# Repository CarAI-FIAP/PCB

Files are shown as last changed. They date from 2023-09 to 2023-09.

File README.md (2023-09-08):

# PCB
Placa em PCB para centralizar as conexões. Projeto em KiCAD

Vista frontal da superficie superior
Vista frontal da superficie inferior
Vista traseira da superficie superior
Vista superior da superficie superior

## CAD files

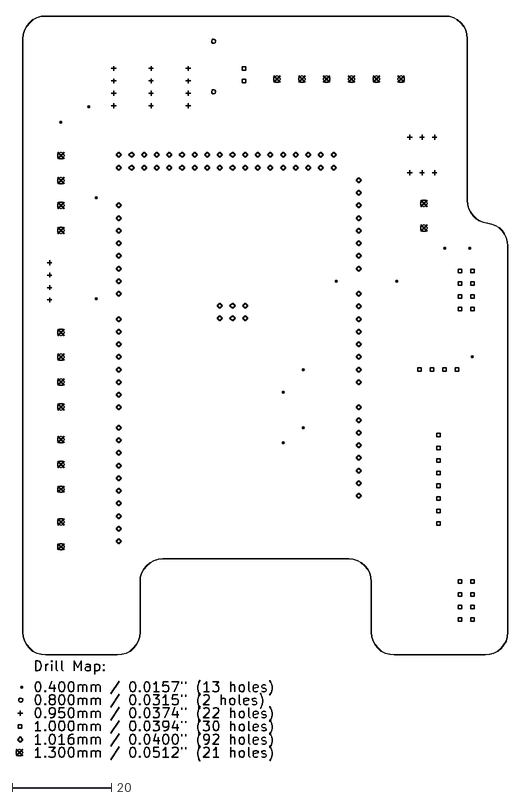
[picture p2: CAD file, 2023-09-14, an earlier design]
V3/Manufatura/PCB V3-PTH-drl_map.dxf
98.9 x 149.9

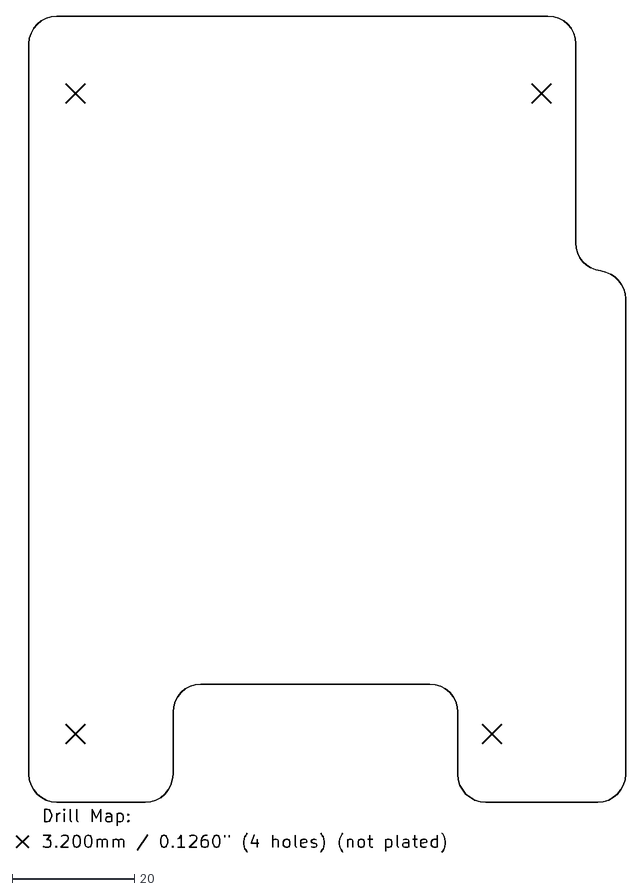
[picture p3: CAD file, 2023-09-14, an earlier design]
V3/Manufatura/PCB V3-NPTH-drl_map.dxf
99.6 x 136.7

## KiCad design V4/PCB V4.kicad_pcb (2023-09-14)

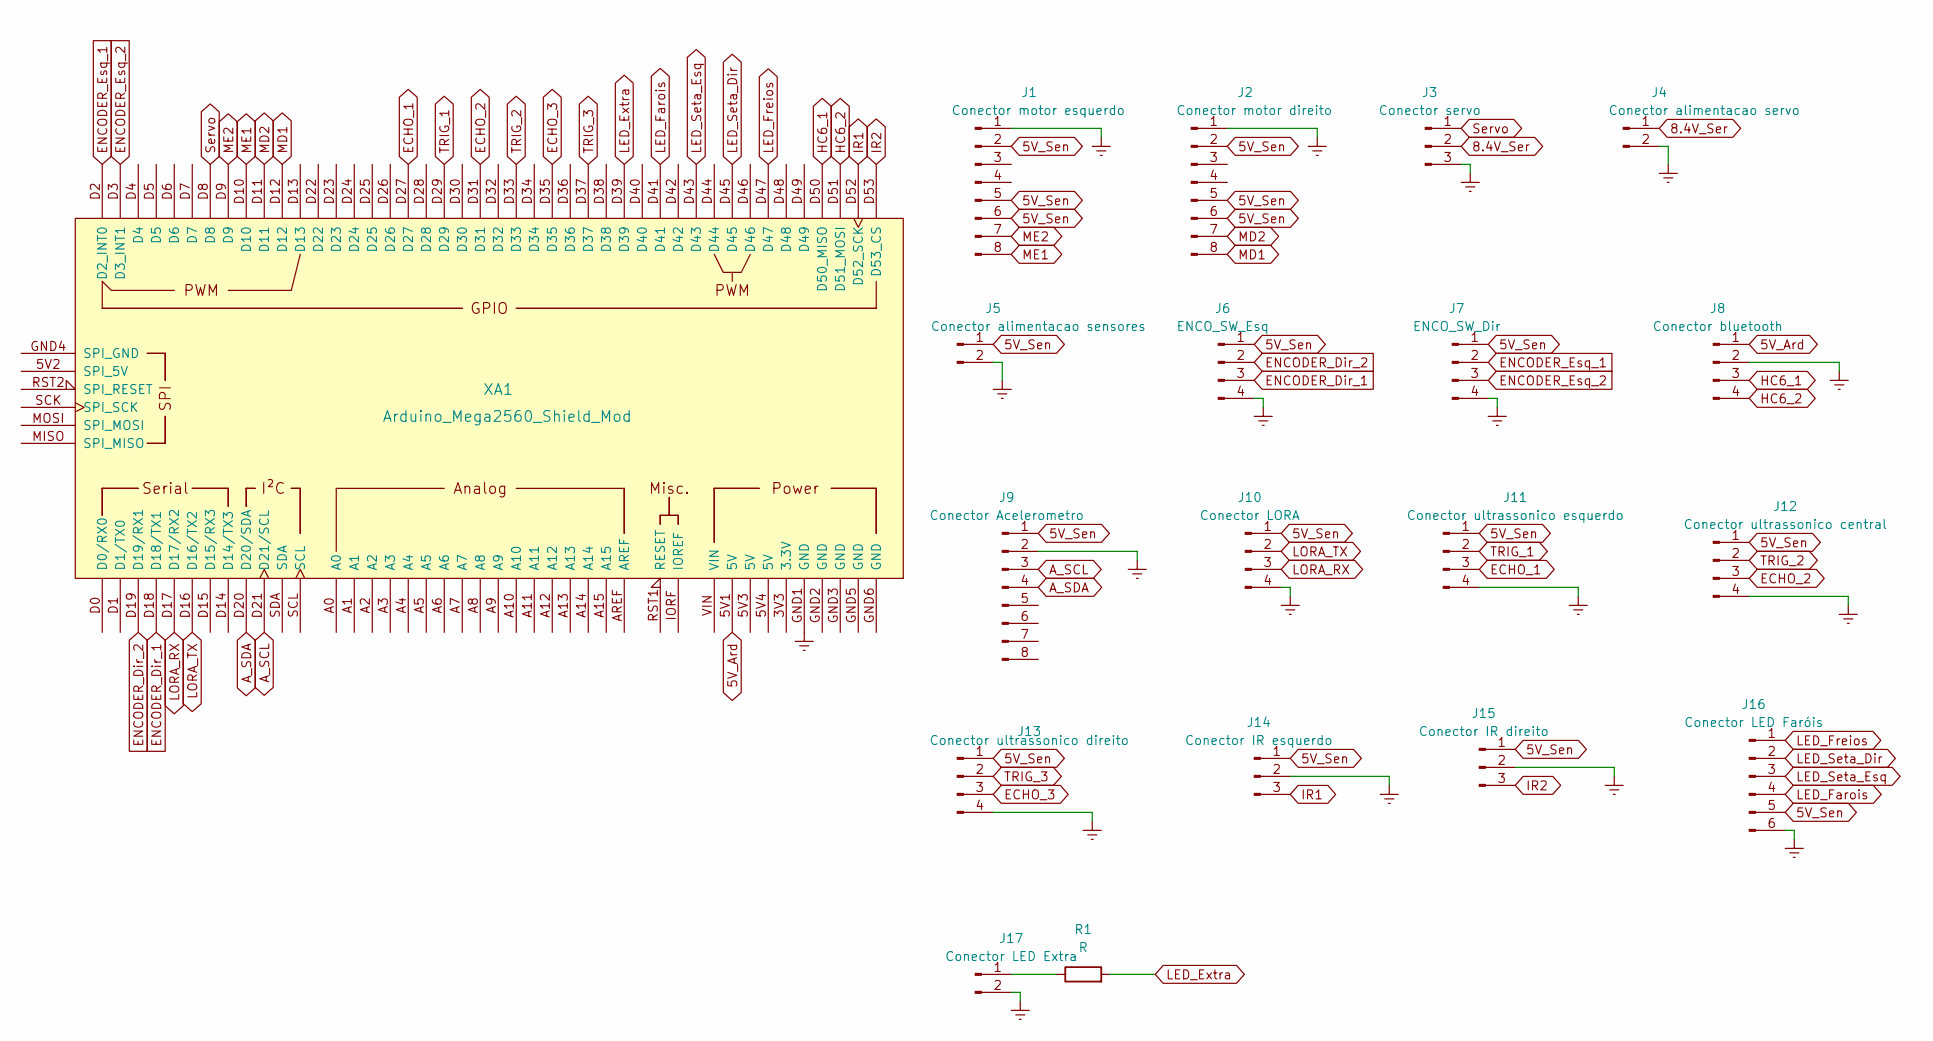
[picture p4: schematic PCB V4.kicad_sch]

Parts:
J1: Conector motor esquerdo; PinSocket_2x04_P2.54mm_Vertical
J2: Conector motor direito; PinSocket_2x04_P2.54mm_Vertical
J3: Conector servo; TerminalBlock_Phoenix_MKDS-1,5-3_1x03_P5.00mm_Horizontal
J4: Conector alimentacao servo; TerminalBlock_Phoenix_MKDS-1,5-2_1x02_P5.00mm_Horizontal
J5: Conector alimentacao sensores; TerminalBlock_Phoenix_MKDS-1,5-2_1x02_P5.00mm_Horizontal
J6: ENCO_SW_Esq; TerminalBlock_Phoenix_MKDS-1,5-4_1x04_P5.00mm_Horizontal
J7: ENCO_SW_Dir; TerminalBlock_Phoenix_MKDS-1,5-4_1x04_P5.00mm_Horizontal
J8: Conector bluetooth; PinSocket_1x04_P2.54mm_Vertical
J9: Conector Acelerometro; PinSocket_1x08_P2.54mm_Vertical
J10: Conector LORA; JST_XH_B4B-XH-A_1x04_P2.50mm_Vertical
J11: Conector ultrassonico esquerdo; JST_XH_B4B-XH-A_1x04_P2.50mm_Vertical
J12: Conector ultrassonico central; JST_XH_B4B-XH-A_1x04_P2.50mm_Vertical
J13: Conector ultrassonico direito; JST_XH_B4B-XH-A_1x04_P2.50mm_Vertical
J14: Conector IR esquerdo; JST_XH_B3B-XH-A_1x03_P2.50mm_Vertical
J15: Conector IR direito; JST_XH_B3B-XH-A_1x03_P2.50mm_Vertical
J16: Conector LED Faróis; TerminalBlock_Phoenix_MKDS-1,5-6_1x06_P5.00mm_Horizontal
J17: Conector LED Extra; JST_XH_B2B-XH-A_1x02_P2.50mm_Vertical
R1: R; R_Axial_DIN0207_L6.3mm_D2.5mm_P10.16mm_Horizontal
XA1: Arduino_Mega2560_Shield_Mod; Arduino_Mega2560_R3_Shield_No_Holes

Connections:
5V_Ard: J8.1, XA1.5V1 (5V)
5V_Sen: J1.2, J1.5, J1.6, J2.2, J2.5, J2.6, J5.1, J6.1, J7.1, J9.1, J10.1, J11.1, J12.1, J13.1, J14.1, J15.1, J16.5
8.4V_Ser: J3.2, J4.1
A_SCL: J9.3, XA1.D21 (D21/SCL)
A_SDA: J9.4, XA1.D20 (D20/SDA)
ECHO_1: J11.3, XA1.D27
ECHO_2: J12.3, XA1.D31
ECHO_3: J13.3, XA1.D35
ENCODER_Dir_1: J6.3, XA1.D18 (D18/TX1)
ENCODER_Dir_2: J6.2, XA1.D19 (D19/RX1)
ENCODER_Esq_1: J7.2, XA1.D2 (D2_INT0)
ENCODER_Esq_2: J7.3, XA1.D3 (D3_INT1)
Earth: J1.1, J2.1, J3.3, J4.2, J5.2, J6.4, J7.4, J8.2, J9.2, J10.4, J11.4, J12.4, J13.4, J14.2, J15.2, J16.6, J17.2, XA1.GND1 (GND)
HC6_1: J8.3, XA1.D50 (D50_MISO)
HC6_2: J8.4, XA1.D51 (D51_MOSI)
IR1: J14.3, XA1.D52 (D52_SCK)
IR2: J15.3, XA1.D53 (D53_CS)
LED_Extra: R1.2, XA1.D39
LED_Farois: J16.4, XA1.D41
LED_Freios: J16.1, XA1.D47
LED_Seta_Dir: J16.2, XA1.D45
LED_Seta_Esq: J16.3, XA1.D43
LORA_RX: J10.3, XA1.D17 (D17/RX2)
LORA_TX: J10.2, XA1.D16 (D16/TX2)
MD1: J2.8, XA1.D12
MD2: J2.7, XA1.D11
ME1: J1.8, XA1.D10
ME2: J1.7, XA1.D9
unnamed: J17.1, R1.1
Servo: J3.1, XA1.D8
TRIG_1: J11.2, XA1.D29
TRIG_2: J12.2, XA1.D33
TRIG_3: J13.2, XA1.D37

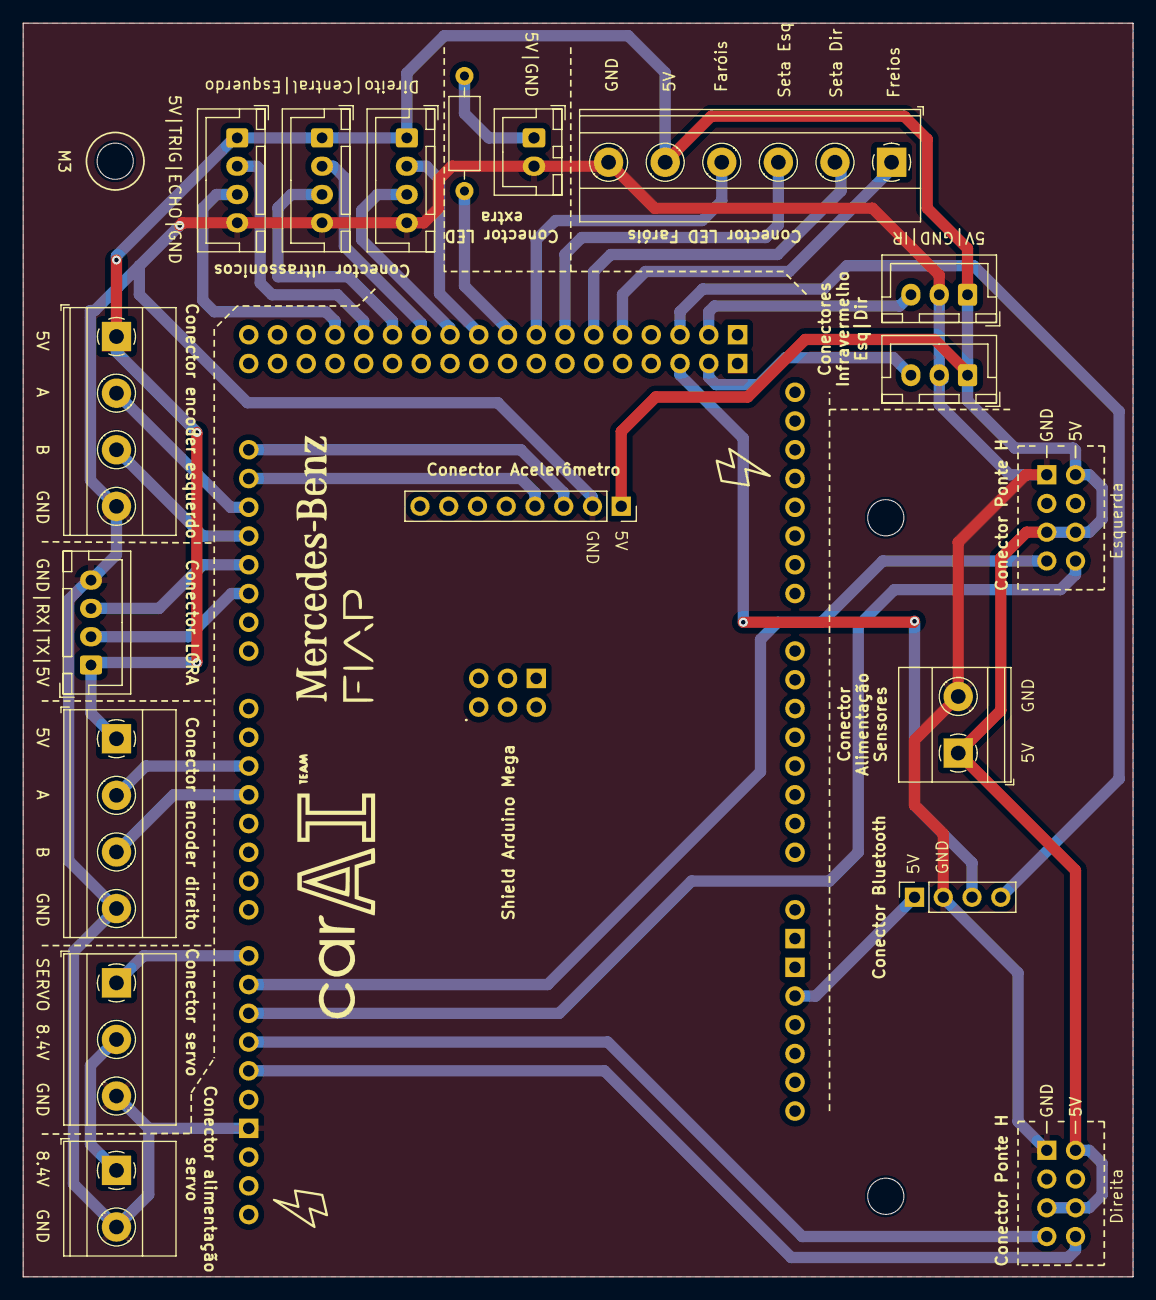
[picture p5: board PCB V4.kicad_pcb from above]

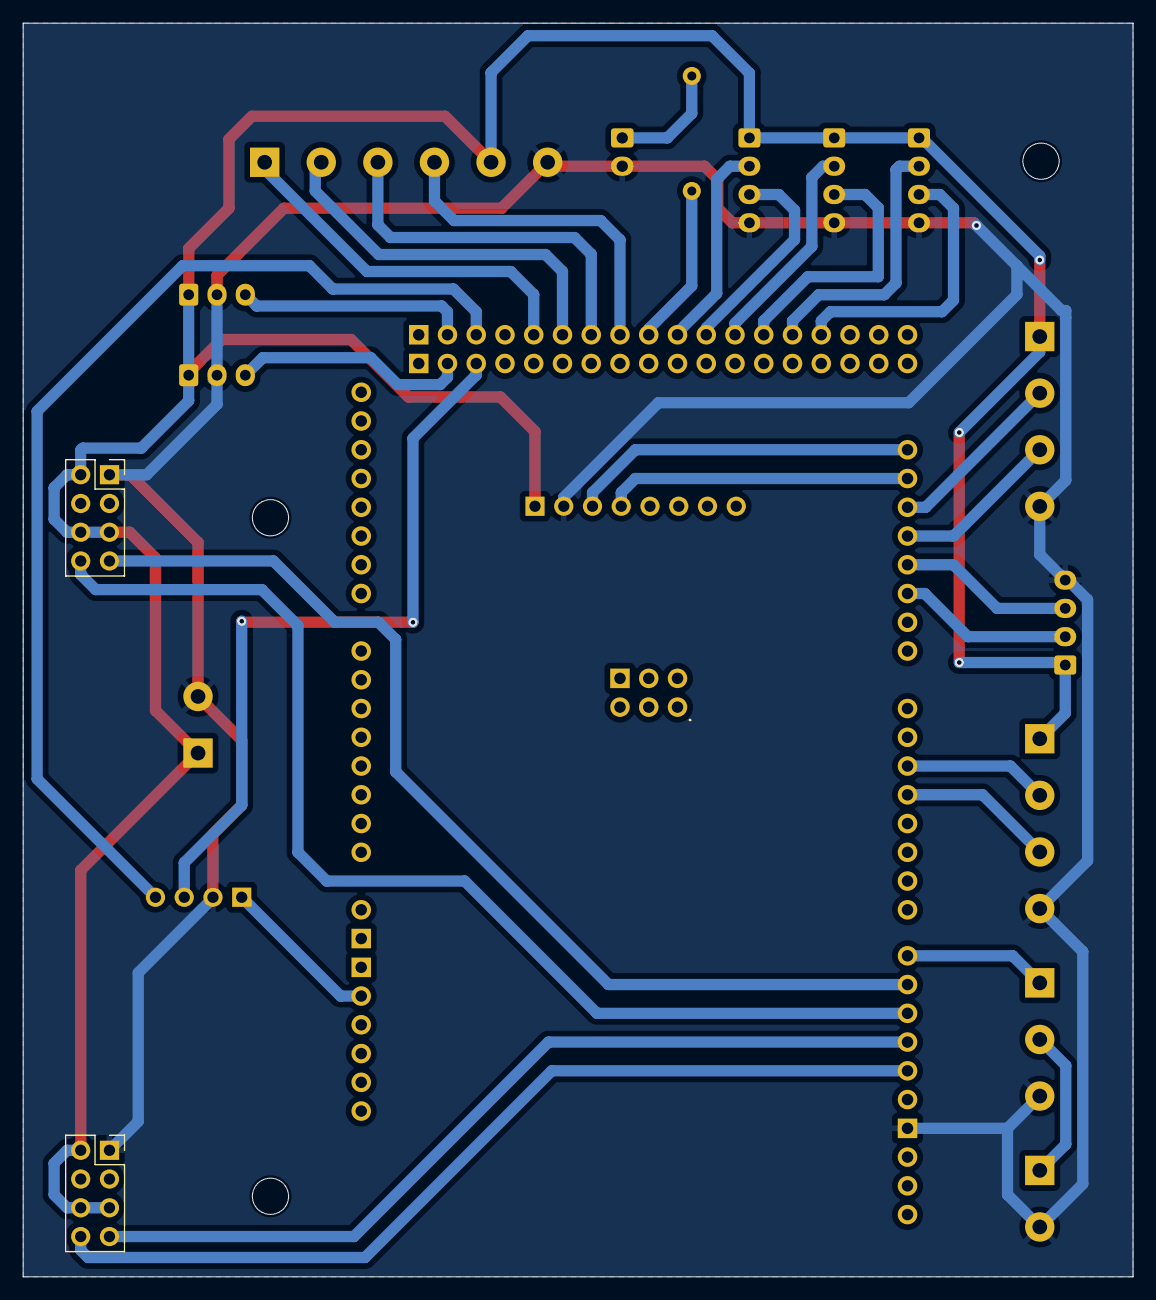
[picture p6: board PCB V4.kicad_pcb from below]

Board: 2 copper layers, 98.0 x 110.7 mm, 19 parts (2 on the bottom side), 33 nets.

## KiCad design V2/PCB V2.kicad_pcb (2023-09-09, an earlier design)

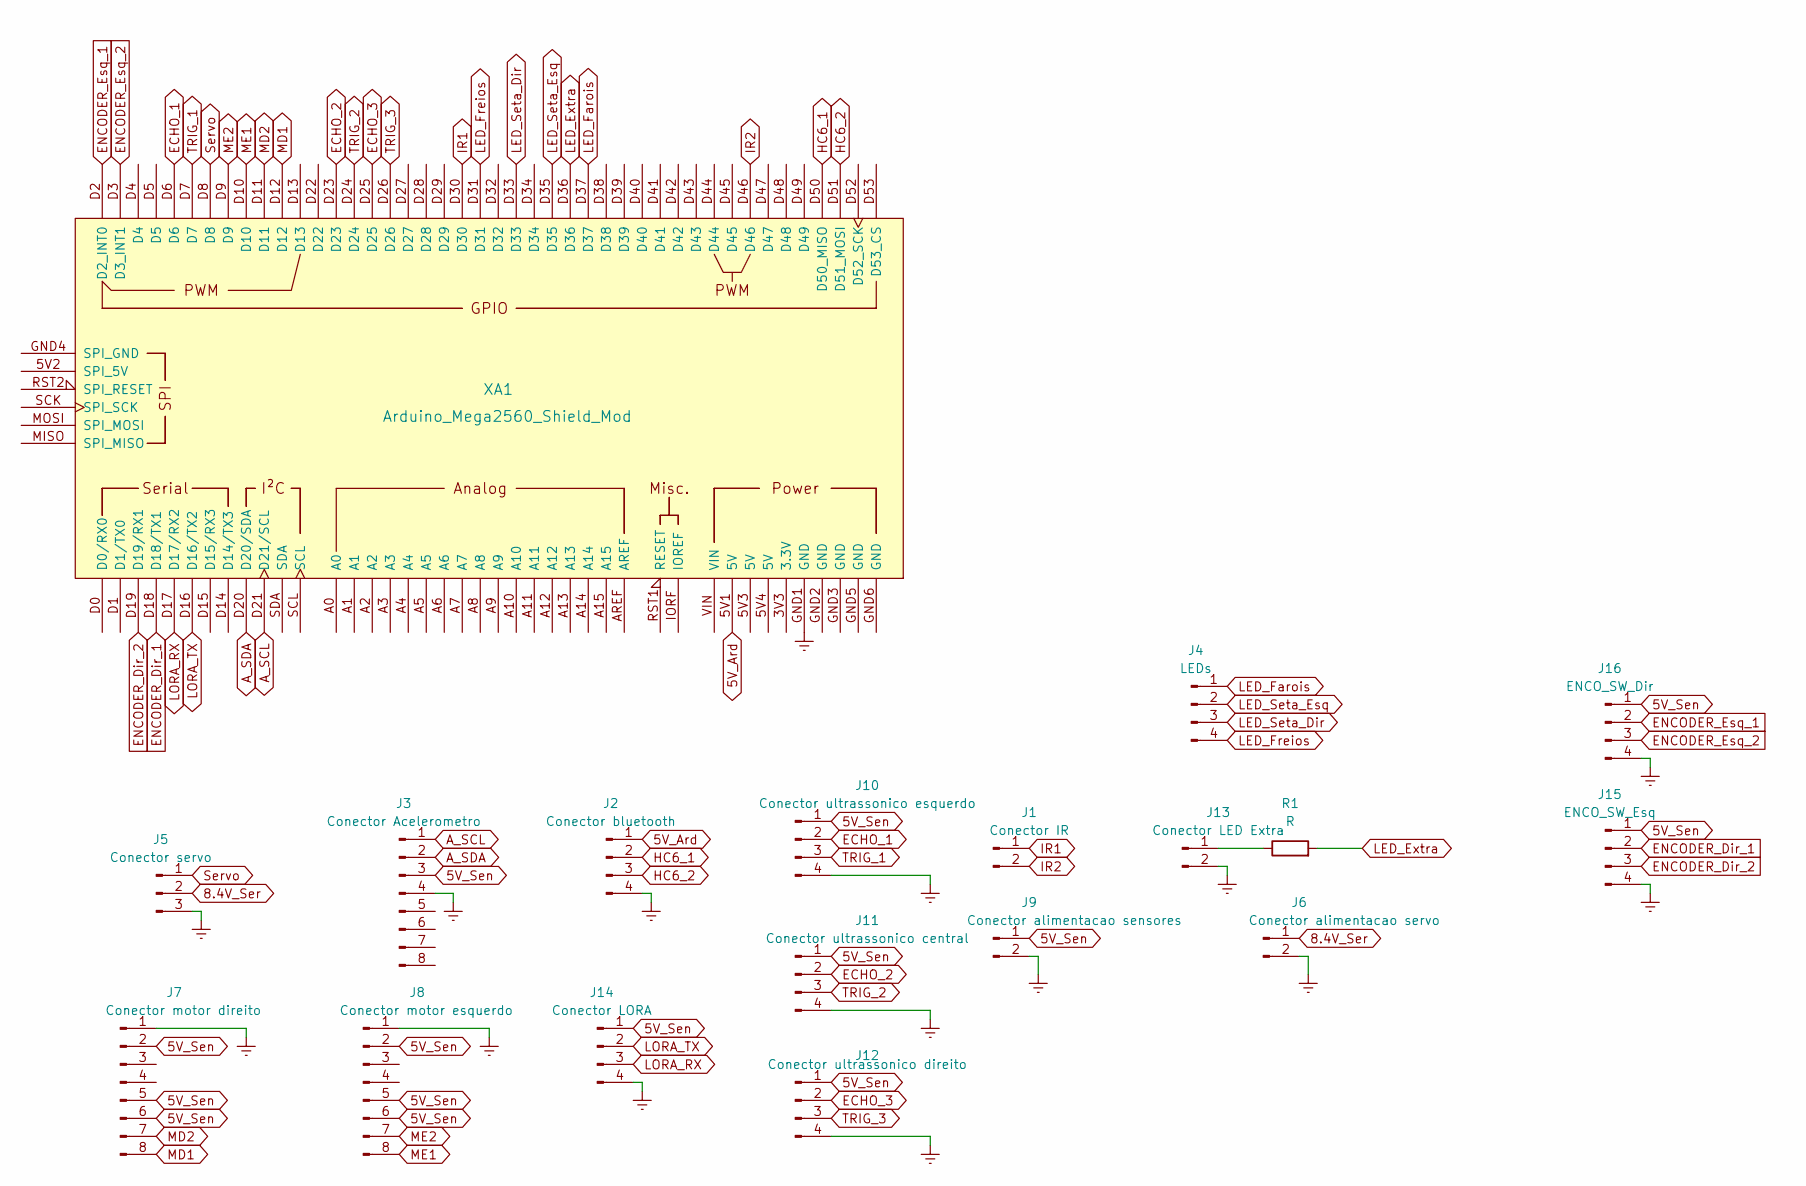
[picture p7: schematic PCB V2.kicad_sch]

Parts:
J1: Conector IR; JST_XH_B2B-XH-A_1x02_P2.50mm_Vertical
J2: Conector bluetooth; PinSocket_1x04_P2.54mm_Vertical
J3: Conector Acelerometro; PinSocket_1x08_P2.54mm_Vertical
J4: LEDs; TerminalBlock_Phoenix_MKDS-1,5-4_1x04_P5.00mm_Horizontal
J5: Conector servo; TerminalBlock_Phoenix_MKDS-1,5-3_1x03_P5.00mm_Horizontal
J6: Conector alimentacao servo; TerminalBlock_Phoenix_MKDS-1,5-2_1x02_P5.00mm_Horizontal
J7: Conector motor direito; PinSocket_2x04_P2.54mm_Vertical
J8: Conector motor esquerdo; PinSocket_2x04_P2.54mm_Vertical
J9: Conector alimentacao sensores; TerminalBlock_Phoenix_MKDS-1,5-2_1x02_P5.00mm_Horizontal
J10: Conector ultrassonico esquerdo; JST_XH_B4B-XH-A_1x04_P2.50mm_Vertical
J11: Conector ultrassonico central; JST_XH_B4B-XH-A_1x04_P2.50mm_Vertical
J12: Conector ultrassonico direito; JST_XH_B4B-XH-A_1x04_P2.50mm_Vertical
J13: Conector LED Extra; JST_XH_B2B-XH-A_1x02_P2.50mm_Vertical
J14: Conector LORA; JST_XH_B4B-XH-A_1x04_P2.50mm_Vertical
J15: ENCO_SW_Esq; TerminalBlock_Phoenix_MKDS-1,5-4_1x04_P5.00mm_Horizontal
J16: ENCO_SW_Dir; TerminalBlock_Phoenix_MKDS-1,5-4_1x04_P5.00mm_Horizontal
R1: R; R_Axial_DIN0207_L6.3mm_D2.5mm_P10.16mm_Horizontal
XA1: Arduino_Mega2560_Shield_Mod; Arduino_Mega2560_R3_Shield_Sem_furo

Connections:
5V_Ard: J2.1, XA1.5V1 (5V)
5V_Sen: J3.3, J7.2, J7.5, J7.6, J8.2, J8.5, J8.6, J9.1, J10.1, J11.1, J12.1, J14.1, J15.1, J16.1
8.4V_Ser: J5.2, J6.1
A_SCL: J3.1, XA1.D21 (D21/SCL)
A_SDA: J3.2, XA1.D20 (D20/SDA)
ECHO_1: J10.2, XA1.D6
ECHO_2: J11.2, XA1.D23
ECHO_3: J12.2, XA1.D25
ENCODER_Dir_1: J15.2, XA1.D18 (D18/TX1)
ENCODER_Dir_2: J15.3, XA1.D19 (D19/RX1)
ENCODER_Esq_1: J16.2, XA1.D2 (D2_INT0)
ENCODER_Esq_2: J16.3, XA1.D3 (D3_INT1)
Earth: J2.4, J3.4, J5.3, J6.2, J7.1, J8.1, J9.2, J10.4, J11.4, J12.4, J13.2, J14.4, J15.4, J16.4, XA1.GND1 (GND)
HC6_1: J2.2, XA1.D50 (D50_MISO)
HC6_2: J2.3, XA1.D51 (D51_MOSI)
IR1: J1.1, XA1.D30
IR2: J1.2, XA1.D46
LED_Extra: R1.2, XA1.D36
LED_Farois: J4.1, XA1.D37
LED_Freios: J4.4, XA1.D31
LED_Seta_Dir: J4.3, XA1.D33
LED_Seta_Esq: J4.2, XA1.D35
LORA_RX: J14.3, XA1.D17 (D17/RX2)
LORA_TX: J14.2, XA1.D16 (D16/TX2)
MD1: J7.8, XA1.D12
MD2: J7.7, XA1.D11
ME1: J8.8, XA1.D10
ME2: J8.7, XA1.D9
unnamed: J13.1, R1.1
Servo: J5.1, XA1.D8
TRIG_1: J10.3, XA1.D7
TRIG_2: J11.3, XA1.D24
TRIG_3: J12.3, XA1.D26

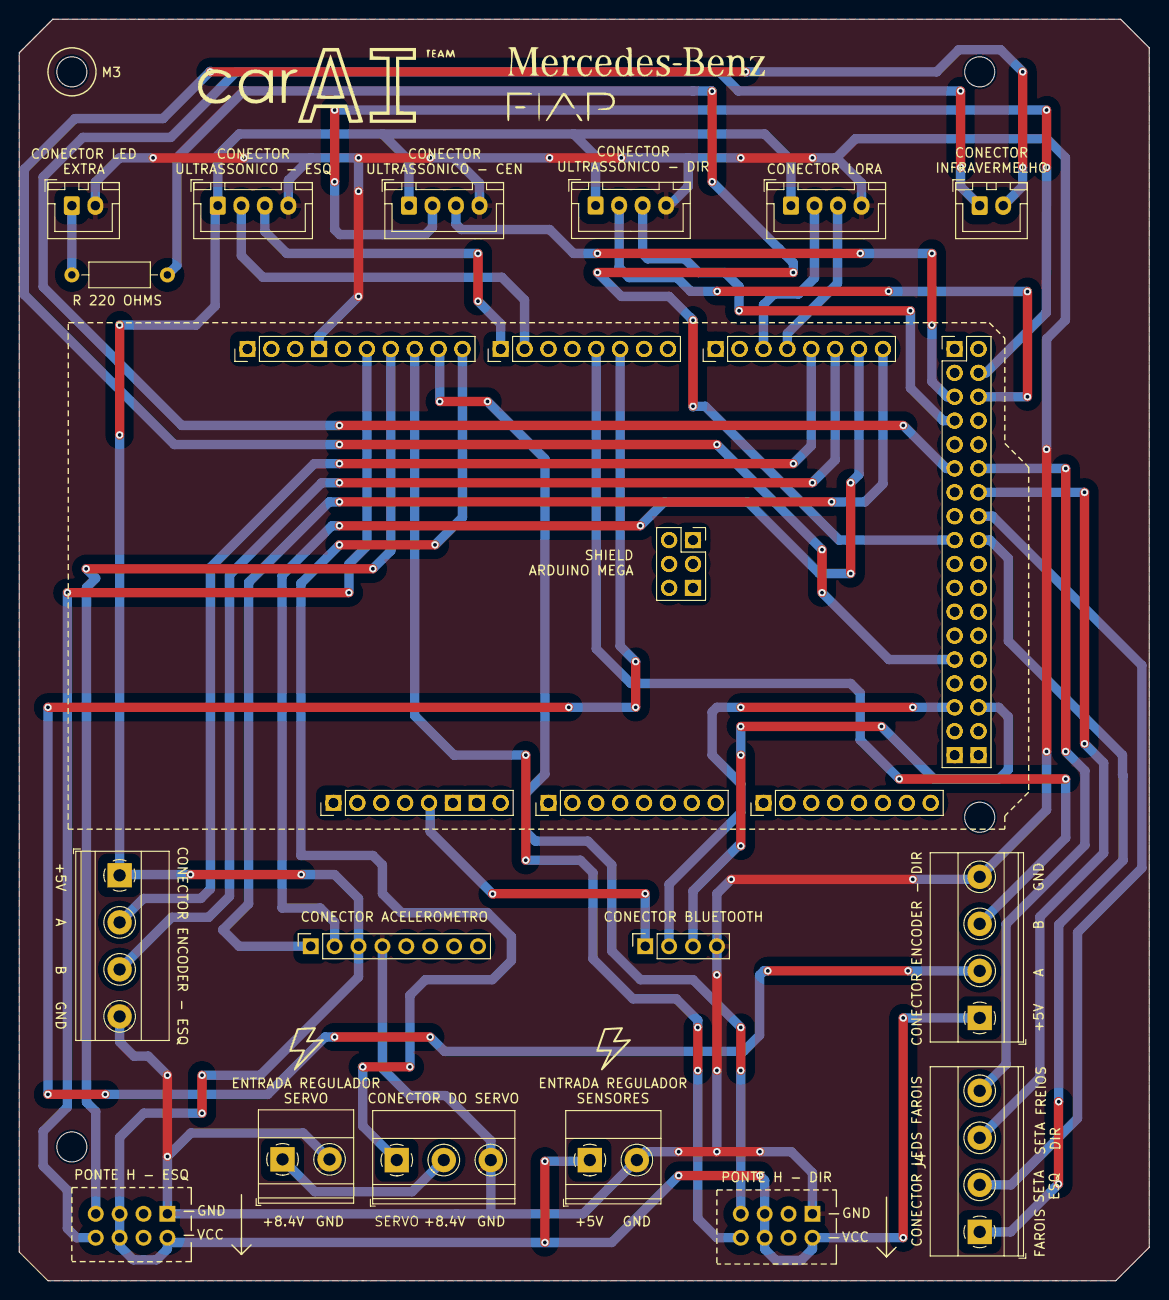
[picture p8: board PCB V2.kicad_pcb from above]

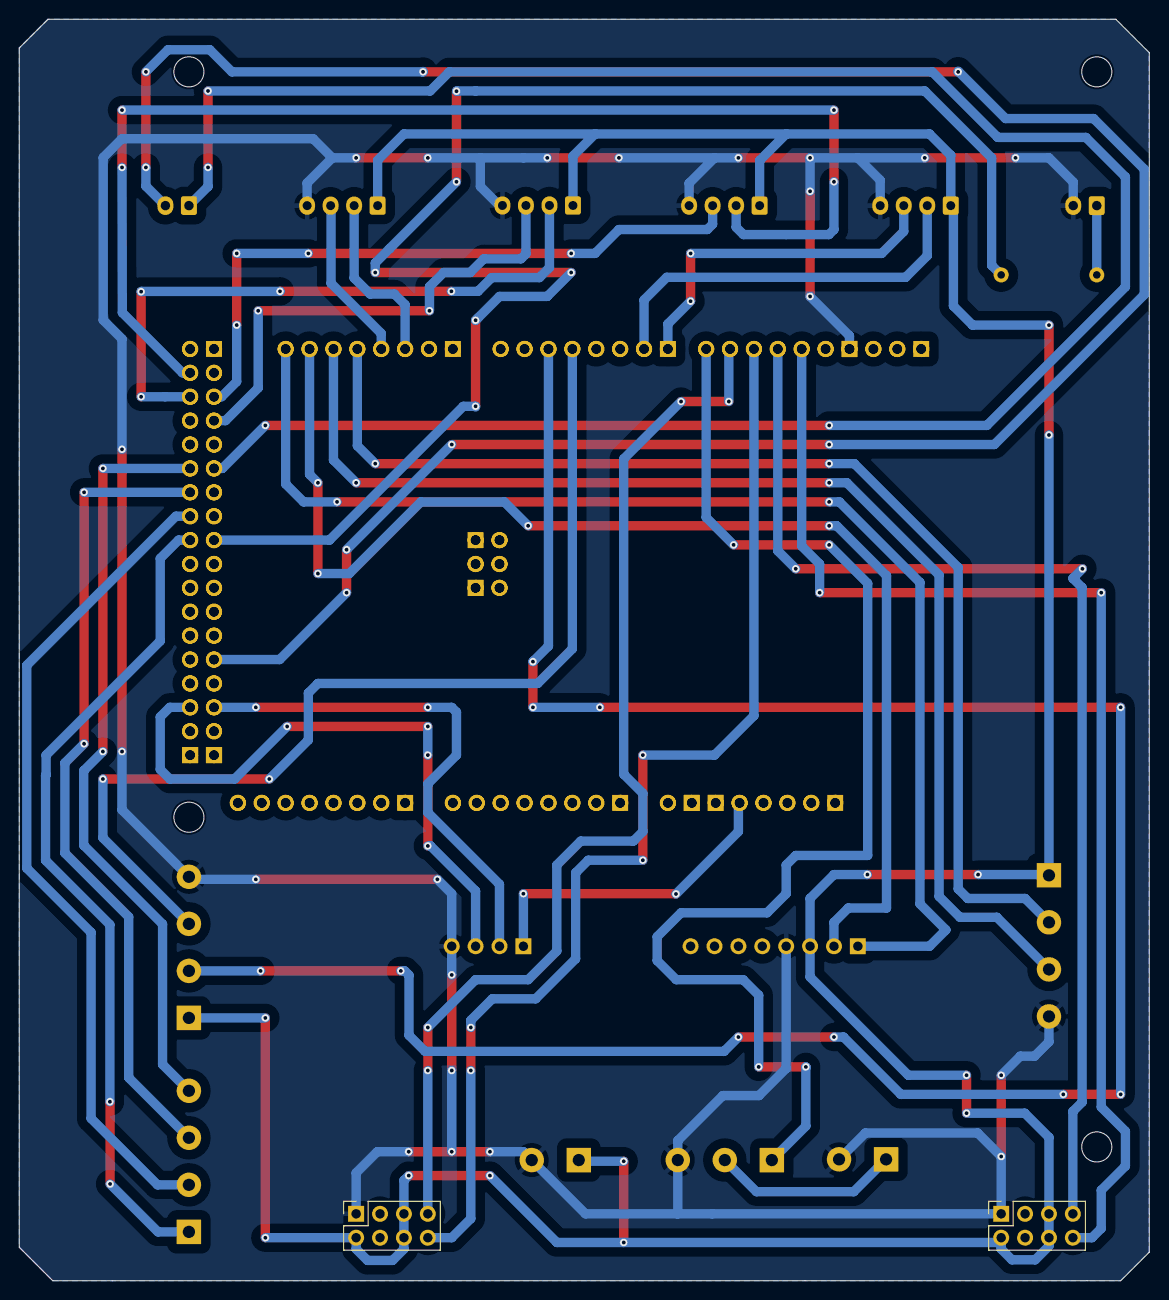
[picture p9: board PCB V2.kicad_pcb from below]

Board: 2 copper layers, 120.1 x 134.1 mm, 18 parts (2 on the bottom side), 33 nets.

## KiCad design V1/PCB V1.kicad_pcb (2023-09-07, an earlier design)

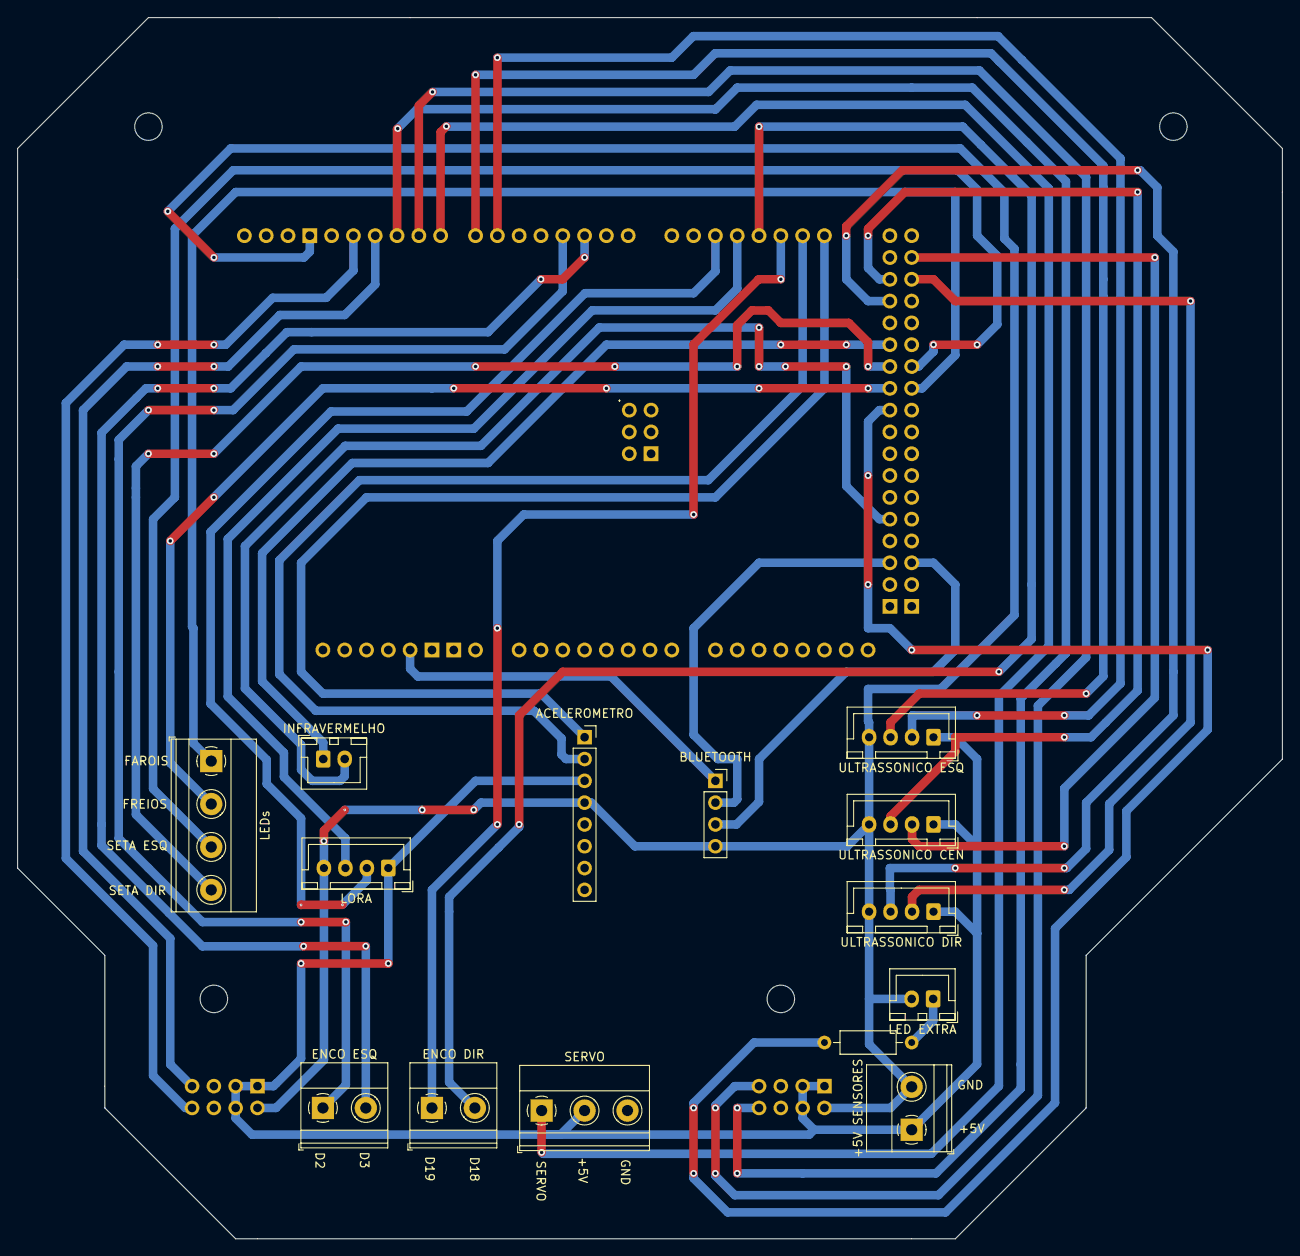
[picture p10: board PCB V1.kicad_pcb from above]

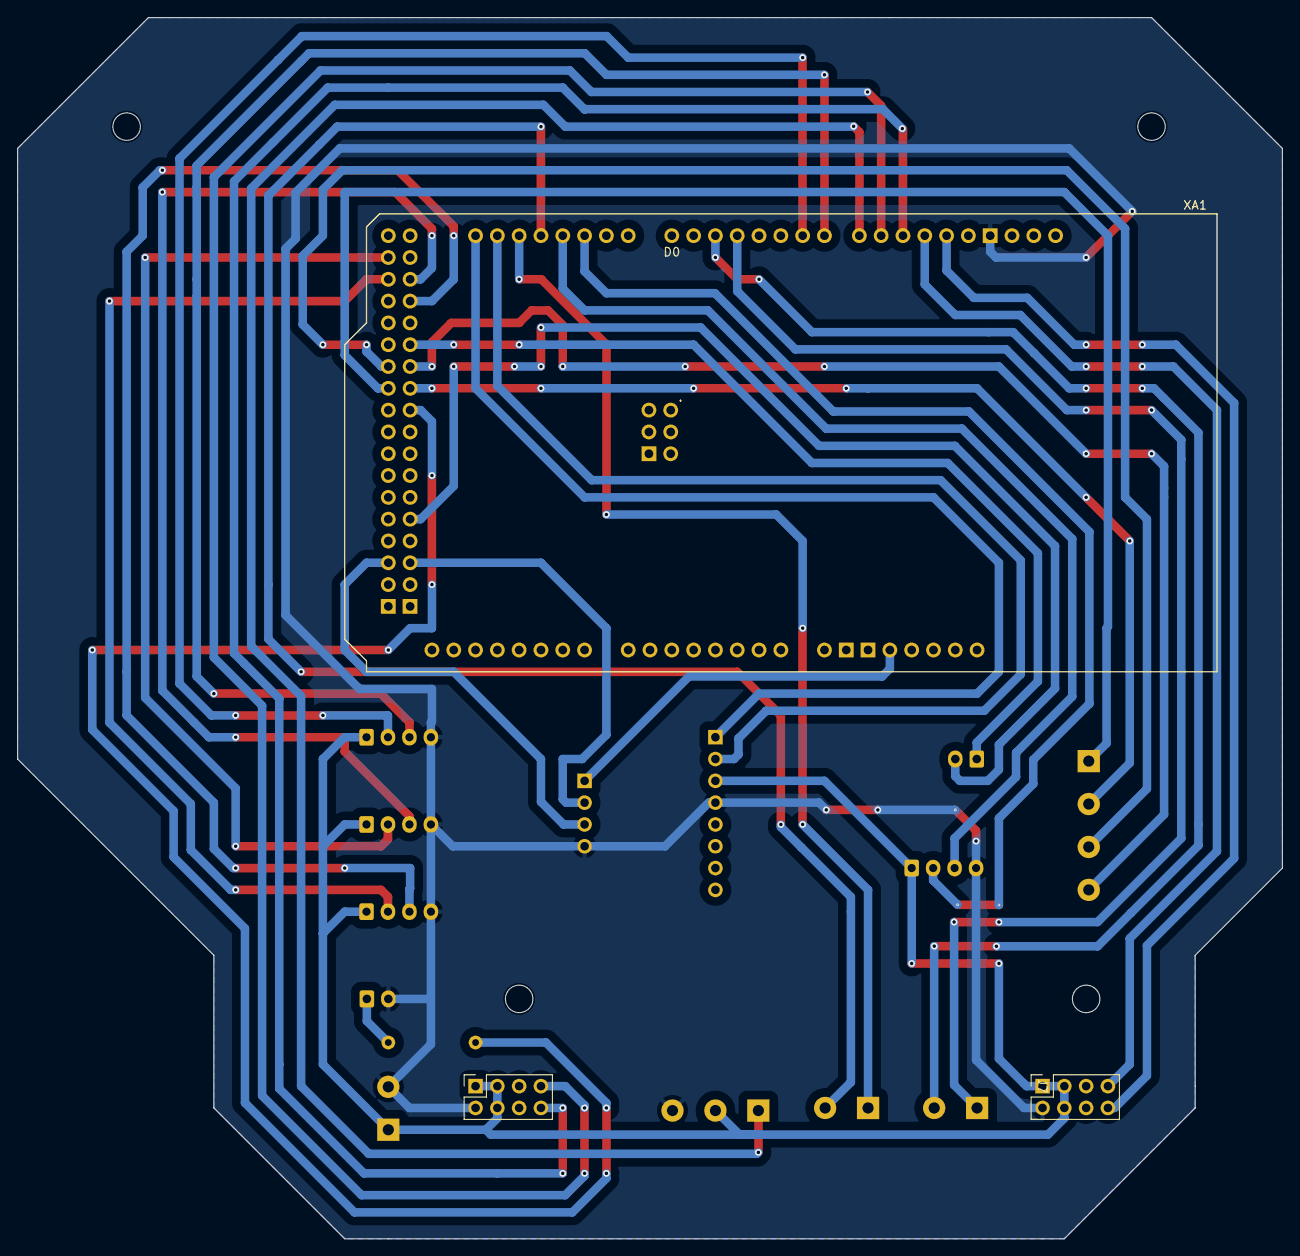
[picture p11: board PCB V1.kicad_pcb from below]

Board: 2 copper layers, 147.3 x 142.2 mm, 17 parts (2 on the bottom side), 32 nets.

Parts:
+5V SENSORES: Conector alimentacao sensores; TerminalBlock_Phoenix_MKDS-1,5-2_1x02_P5.00mm_Horizontal
ACELEROMETRO: Conector Acelerometro; PinSocket_1x08_P2.54mm_Vertical
BLUETOOTH: Conector bluetooth; PinSocket_1x04_P2.54mm_Vertical
ENCO DIR: ENCO_SW_Dir; TerminalBlock_Phoenix_MKDS-1,5-2_1x02_P5.00mm_Horizontal
ENCO ESQ: ENCO_SW_Esq; TerminalBlock_Phoenix_MKDS-1,5-2_1x02_P5.00mm_Horizontal
INFRAVERMELHO: Conector IR; JST_XH_B2B-XH-A_1x02_P2.50mm_Vertical
J7: PONTA H 1; PinSocket_2x04_P2.54mm_Vertical
LED EXTRA: Conector LED Extra; JST_XH_B2B-XH-A_1x02_P2.50mm_Vertical
LEDs: LEDs; TerminalBlock_Phoenix_MKDS-1,5-4_1x04_P5.00mm_Horizontal
LORA: Conector LORA; JST_XH_B4B-XH-A_1x04_P2.50mm_Vertical
PONTE H 2: Conector motor esquerdo; PinSocket_2x04_P2.54mm_Vertical
R1: R; R_Axial_DIN0207_L6.3mm_D2.5mm_P10.16mm_Horizontal
SERVO: Conector servo; TerminalBlock_Phoenix_MKDS-1,5-3_1x03_P5.00mm_Horizontal
ULTRASSONICO CEN: Conector ultrassonico central; JST_XH_B4B-XH-A_1x04_P2.50mm_Vertical
ULTRASSONICO DIR: Conector ultrassonico direito; JST_XH_B4B-XH-A_1x04_P2.50mm_Vertical
ULTRASSONICO ESQ: Conector ultrassonico esquerdo; JST_XH_B4B-XH-A_1x04_P2.50mm_Vertical
XA1: Arduino_Mega2560_Shield_Mod; Arduino_Mega2560_R3_Shield_Sem_furo

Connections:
5V_Ard: BLUETOOTH.1, XA1.5V1 (5V)
5V_Sen: +5V SENSORES.1, ACELEROMETRO.3, J7.1, J7.3, J7.4, LORA.1, PONTE H 2.1, PONTE H 2.3, PONTE H 2.4, SERVO.2, ULTRASSONICO CEN.1, ULTRASSONICO DIR.1, ULTRASSONICO ESQ.1
A_SCL: ACELEROMETRO.1, XA1.D21 (D21/SCL)
A_SDA: ACELEROMETRO.2, XA1.D20 (D20/SDA)
ECHO_1: ULTRASSONICO ESQ.2, XA1.D6
ECHO_2: ULTRASSONICO CEN.2, XA1.D23
ECHO_3: ULTRASSONICO DIR.2, XA1.D25
Earth: +5V SENSORES.2, ACELEROMETRO.4, BLUETOOTH.4, J7.2, LED EXTRA.2, LORA.4, PONTE H 2.2, SERVO.3, ULTRASSONICO CEN.4, ULTRASSONICO DIR.4, ULTRASSONICO ESQ.4, XA1.GND1 (GND)
HC6_1: BLUETOOTH.2, XA1.D50 (D50_MISO)
HC6_2: BLUETOOTH.3, XA1.D51 (D51_MOSI)
IR1: INFRAVERMELHO.1, XA1.D30
IR2: INFRAVERMELHO.2, XA1.D46
LED_Extra: R1.2, XA1.D36
LORA_RX: LORA.3, XA1.D17 (D17/RX2)
LORA_TX: LORA.2, XA1.D16 (D16/TX2)
MD1: J7.8, XA1.D12
MD2: J7.7, XA1.D11
ME1: PONTE H 2.8, XA1.D10
ME2: PONTE H 2.7, XA1.D9
unnamed: ENCO ESQ.1, XA1.D3 (D3_INT1)
unnamed: ENCO ESQ.2, XA1.D2 (D2_INT0)
unnamed: ENCO DIR.1, XA1.D19 (D19/RX1)
unnamed: ENCO DIR.2, XA1.D18 (D18/TX1)
unnamed: LED EXTRA.1, R1.1
unnamed: LEDs.1, XA1.D35
unnamed: LEDs.2, XA1.D34
unnamed: LEDs.3, XA1.D33
unnamed: LEDs.4, XA1.D32
Servo: SERVO.1, XA1.D8
TRIG_1: ULTRASSONICO ESQ.3, XA1.D7
TRIG_2: ULTRASSONICO CEN.3, XA1.D24
TRIG_3: ULTRASSONICO DIR.3, XA1.D26

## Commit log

2023-09-06 feat: pcb layout e conexoes no esquematico
    [PCB.kicad_pcb, PCB.kicad_sch]
2023-09-06 feat: criacao do pcb
    [PCB.kicad_pcb, PCB.kicad_sch]
2023-09-07 feat: inicio da nova versao da pcb
    [PCB V2.kicad_pcb, PCB.kicad_pcb, PCB.kicad_sch]
2023-09-08 feat: finalizacao da versao 2 da pcb
    [PCB V2.kicad_pcb, PCB.kicad_sch]
2023-09-08 fix: criacao de pasta "renders"
2023-09-08 fix: adicao de uma foto no README
2023-09-08 fix: adicao de imagens ao README
2023-09-08 fix: ajuste de imagens no README
2023-09-08 fix: mudanca esquematico leds farois
    [PCB.kicad_sch]
2023-09-09 fix: adição da entrada 8.4V do servo e outros
    [PCB V2.kicad_pcb, PCB.kicad_sch]
2023-09-09 feat: criacao da versao 3 da pcb e organizacao
    [PCB V1.kicad_pcb, PCB V1.kicad_sch, PCB V2.kicad_pcb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]
2023-09-09 feat: criação dos arquivos de manufatura
    [PCB V3.kicad_pcb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]
2023-09-14 feat: criação do V4 com corte quadrado
    [PCB V3-NPTH-drl_map.dxf, PCB V3-PTH-drl_map.dxf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]
2023-09-14 fix: compactação dos arquivos de manufatura
